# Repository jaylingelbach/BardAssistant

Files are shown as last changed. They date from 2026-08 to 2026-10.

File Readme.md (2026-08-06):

# BardAssistant – The Bard’s Assistant (ESP32-S3)

A tiny “Vicious Mockery” companion built on an ESP32-S3 DevKitM-1.

Right now it:

- Uses **buttons** to request insults (`Random`, `Next`, `Prev`, `Sleep (hold)`).
- Uses a **NeoPixel** as a simple state indicator:
  - **Blue** – Booting
  - **Green** – Idle (ready for button presses)
  - **Yellow** – Updating (pretending to “do work”)
  - **Magenta ** – Updating
- Prints insults and status info over **Serial** (`115200` baud).

Planned:

- Add a **Waveshare 2.13" E-Ink** screen and render insults + header there.
- Power stuff / sleep / wake on long-press.

---

## Hardware

Current setup:

- **Board**: ESP32-S3 DevKitM-1
- **LED**:
  - 1x NeoPixel RGB LED
  - Data pin: `GPIO 21`
- **Buttons** (tactile switches to GND, using `INPUT_PULLUP` in code):
  - Random: `GPIO 4`
  - Next: `GPIO 5`
  - Prev: `GPIO 6`
  - Sleep: `GPIO 7`

Planned display (not wired/used yet):

- Waveshare 2.13" E-Ink Display HAT V4
  - 250x122, SPI, partial refresh
  - Will eventually show:
    - Title screen / logo
    - Current insult text
    - Basic “source” info (`Random / Next / Prev`)

---

## Firmware Overview

All of this lives in `src/main.cpp` for now, plus small modules:

- `lib/button/` – debounced button input
- `lib/led/` – NeoPixel status LED

### Application States

```cpp
enum class ApplicationState { Boot, Idle, Updating };
```

- **Boot**
  - LED: Blue (`ledShowBoot()`)
  - After ~2 seconds, transitions to **Idle**

- **Idle**
  - LED: Green (`ledShowIdle()`)
  - Listens for button taps:
    - Random → start a “Random insult” operation
    - Next → move forward through insult history (or draw new)
    - Prev → move backward through insult history

- **Updating**
  - LED: Yellow (`ledShowUpdating()`)
  - Simulates “work” with a small delay (`MOCK_WORK_MS`)
  - When “done”, applies the insult index and goes back to Idle

### Buttons & Events

Buttons are debounced and produce high-level events (from `button` module):

```cpp
enum class ButtonEvent { None, Tap, HoldStart, HoldEnd };
```

- Tap → triggers Random / Next / Prev operations _while in Idle_
- Sleep:
  - `HoldStart` is wired to eventually trigger deep sleep (`enterSleep()`),
    currently just logs.

### Insults, Deck, and History (Serial Only for Now)

- `insults[]` – array of `const char*` insult strings.
- **Deck**:
  - Shuffled list of indices, ensures “Random” doesn’t repeat until all have been used.

- **History**:
  - Remembers which insults have been shown.
  - `Next` / `Prev` navigate the history when possible.
  - `Next` at the end of history draws a new insult from the deck.

Rendering is currently:

- `renderTitleScreen()` – ASCII art + project name on boot (Serial only).
- `renderInsultAtIndex(...)` – logs:
  - Which insult index is active
  - The insult text itself
  - Optional context (`Random` vs `Next` vs `Prev`)

Later, these will be redirected to the E-Ink screen instead of (or in addition to) Serial.

---

## PlatformIO – Commands I Keep Forgetting

> All commands assume you’re in the project root (where `platformio.ini` lives).

### Build

**Generic:**

```bash
pio run
```

**Specific environment (ESP32-S3 DevKitM-1):**

```bash
pio run -e esp32-s3-devkitm-1
```

---

### Upload Firmware

**Generic upload for default env:**

```bash
pio run -t upload
```

**Upload to ESP32-S3 DevKitM-1 explicitly:**

```bash
pio run -e esp32-s3-devkitm-1 -t upload
```

---

### Erase Flash

Useful when things get weird or after changing flash layout / partitions:

```bash
pio run -e esp32-s3-devkitm-1 -t erase
```

Then re-upload your firmware.

---

### Clean Build Artifacts

If builds start acting cursed:

```bash
pio run -t clean
```

---

### Serial Monitor

**On my Mac / current setup:**

```bash
pio device monitor -p /dev/cu.usbmodem1101 -b 115200
```

Generic form:

```bash
pio device monitor -p <PORT> -b 115200
```

Hit `Ctrl + C` to exit.

---

## Development Notes

- Buttons are wired **to GND** and use `INPUT_PULLUP`:
  - Released → HIGH
  - Pressed → LOW

- Long-press on Sleep is **debounced and recognized**.
- State machine and insult logic are conceptually separate:
  - `main.cpp` handles:
    - Board setup
    - State transitions
    - Calling “work engine” functions

- Insult/deck/history logic lives in `lib/insults/`

---

## Sleep / Wake Behavior

### Entering Sleep

1. **Hold** the Sleep button to arm sleep mode (LED turns magenta).
2. **Release** the button to enter deep sleep.

This "hold to sleep, release to confirm" gesture prevents accidental sleep entry.

### Waking Up

1. **Tap** or **press** the Sleep button while asleep — the pin goes LOW and triggers a wake.
2. The ESP32-S3 boots from reset and runs `setup()` again.
3. Optionally, wake reason can be detected via `esp_sleep_get_wakeup_cause()`.

## Setup (Fresh Clone)

```bash
# Clone
git clone https://github.com/jaylingelbach/BardAssistant.git
cd BardAssistant

# Build (default env)
pio run

# Or build for the ESP32-S3 env explicitly
pio run -e esp32-s3-devkitm-1

# Upload
pio run -e esp32-s3-devkitm-1 -t upload

# Monitor
pio device monitor -p /dev/cu.usbmodem1101 -b 115200
```

## Current display panel being used

- GxEPD2_213_B74

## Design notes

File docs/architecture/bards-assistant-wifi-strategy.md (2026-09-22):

# Bard's Assistant — Wi-Fi Provisioning & Web Mode Strategy

## Purpose

Record the intended Wi-Fi architecture so future changes do not mix up **Wi-Fi provisioning** with **Web Mode**.

mDNS belongs to Web Mode, not Wi-Fi provisioning.

## Mental Model

Bard's Assistant is **offline-first**. Normal use does not turn on Wi-Fi or the web server.

---

## Provisioning Flow

### First-time setup (no saved credentials)

```text
IDLE
 |
 | Provisioning gesture held 2s
 v
provisioningStart()
 |
 +-- Open WiFiManager captive portal (non-blocking)
 +-- Display connection instructions
 |
 | User connects phone to "BardsAssistant" AP,
 | submits credentials at 192.168.4.1
 |
 v
provisioningPoll() → SUCCESS
 |
 v
enterWebModeAlreadyConnected()
 |
 +--[SUCCESS]-----------------------------+
 |   Start mDNS (bardsassistant.local)   |
 |   Start WebServerManager              |
 |   Display: "WiFi saved!               |
 |             bardsassistant.local      |
 |             <IP>"                     |
 |                                       v
 +--[MDNS_FAILED]-------------------> WEB MODE
     Start WebServerManager
     Display: "WiFi saved!
               <IP>"
```

### Re-provisioning (credentials already saved)

```text
IDLE
 |
 | Provisioning gesture held 2s
 v
hasKnownNetwork() → true
 |
 v
ProvisioningConfirmation state
 |
 | Next tap → confirm
 | Sleep tap → cancel → IDLE
 v
provisioningStart()
 ... (same as first-time setup above)
```

---

## Web Mode Flow

### Entering Web Mode (gesture)

```text
IDLE
 |
 | Web Mode gesture held 2s
 v
enterWebMode()
 |
 +-- WiFi.begin() with saved credentials
 +-- Wait for WL_CONNECTED + non-zero IP
 +-- MDNS.begin(BARDS_HOSTNAME)
 +-- WebServerManager.start()
 |
 v
WEB MODE
```

### Exiting Web Mode

```text
WEB MODE
 |
 | Web Mode gesture held 2s
 v
WebServerManager.stop()
exitWebMode()
 |
 +-- MDNS.end()
 +-- WiFi.disconnect() (credentials preserved)
 |
 v
IDLE
```

---

## Key Functions

### `provisioningStart()` / `provisioningPoll()`

Wraps WiFiManager's non-blocking captive portal. `provisioningPoll()` is called
every loop tick while in the `Provisioning` state and returns:

- `IN_PROGRESS` — portal is open, waiting for user
- `SUCCESS` — credentials submitted and WiFi connected
- `FAILED` — timeout expired, or credentials were submitted but connection failed
- `CANCELLED` — portal closed without a submission

### `enterWebMode()`

Used for the gesture-triggered Web Mode path. Calls `WiFi.begin()` with saved
credentials and waits up to 5 seconds for both `WL_CONNECTED` and a non-zero IP
before starting mDNS.

### `enterWebModeAlreadyConnected()`

Used exclusively after a successful provisioning. Skips `WiFi.begin()` entirely
since WiFiManager already holds a live connection. Only starts mDNS.

### `hasKnownNetwork()`

Calls `WiFi.mode(WIFI_STA)` before querying `wm.getWiFiIsSaved()`. The WiFi
driver must be initialized first or the query returns stale data.

### `resetWiFiSettings()`

Clears both the ESP32's own WiFi NVS store (`WiFi.disconnect(true, true)`) and
WiFiManager's NVS namespace (`wm.resetSettings()`). Both must be cleared — they
are separate stores.

---

## Responsibility Boundaries

### NetworkManager

Owns:

- Wi-Fi provisioning (captive portal lifecycle)
- Wi-Fi connection/disconnection
- mDNS lifecycle
- `BARDS_HOSTNAME` constant

### WebServerManager

Owns:

- HTTP server
- HTTP routes and request/response handling
- Web UI/API serving

Does **not** own:

- Wi-Fi provisioning
- LittleFS persistence
- Deck business logic

### Main / Application Layer

Owns:

- User-driven state transitions (`ApplicationState`)
- Deciding when to enter/exit provisioning and Web Mode
- Coordinating managers

---

## Important Invariants

**mDNS belongs to Web Mode.**
Do not start `MDNS.begin()` in provisioning code. The question to ask is:

> "Is the device entering Web Mode?"

If **no** → don't start mDNS.
If **yes** → `enterWebMode()` or `enterWebModeAlreadyConnected()` handles it.

**`hasKnownNetwork()` requires an initialized WiFi driver.**
Always ensure `WiFi.mode(WIFI_STA)` has been called before querying saved
credentials, or the result is unreliable.

**Two NVS stores, one reset.**
`wm.resetSettings()` alone does not fully clear credentials. Always pair it with
`WiFi.disconnect(true, true)`.

---

## Hostname

The hostname is defined as `BARDS_HOSTNAME` in `networkManager.h`:

```cpp
static constexpr const char *BARDS_HOSTNAME = "bardsassistant";
```

This is used for:
- The WiFiManager AP password
- `MDNS.begin()`
- Display messages

Change it in one place to update everywhere.

---

## OTA Authentication (Deferred)

ElegantOTA is integrated but has no authentication — `/update` is open to anyone
on the network. Acceptable during development on a trusted network, but must be
addressed before shipping.

When the production board is finalized, add `ElegantOTA.setAuth()` sourcing
credentials from NVS rather than hardcoding them.

### ElegantOTA License (AGPL-3.0)

ElegantOTA is AGPL-3.0. Private use on your own device carries no obligation.
If you distribute firmware to others, AGPL requires making the complete source
available to recipients. Before shipping to anyone else, either open-source
under a compatible license or purchase the ElegantOTA Pro commercial license.

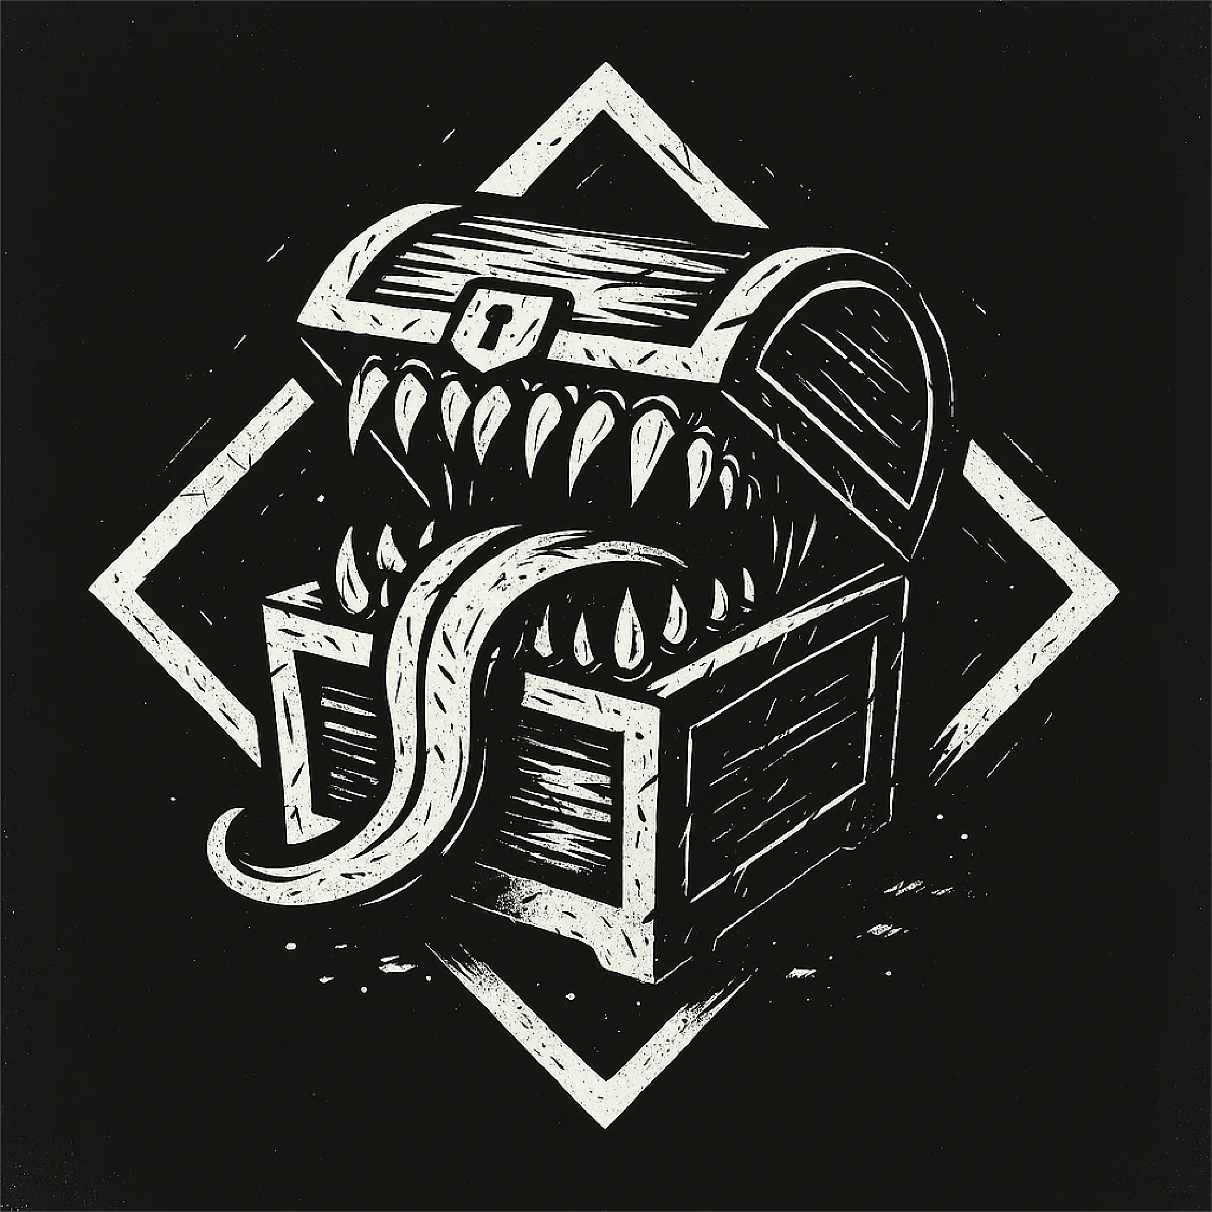
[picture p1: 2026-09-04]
KiCad/BardsAssistant/mimic.png

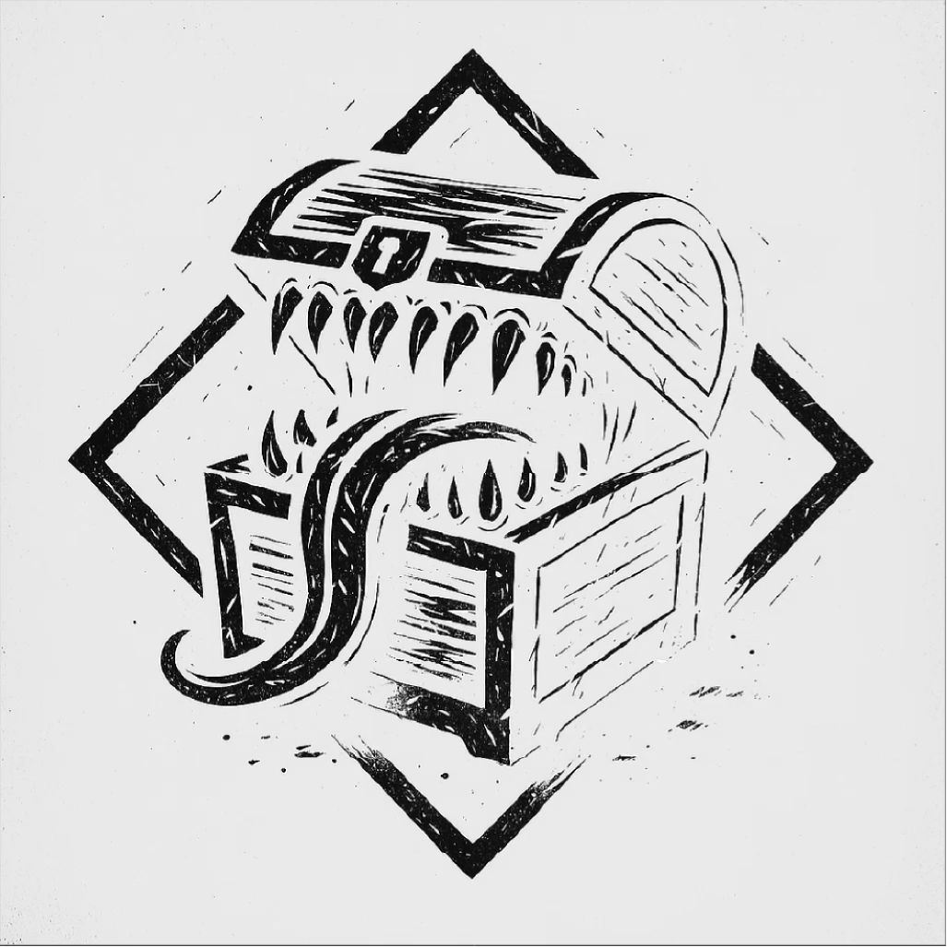
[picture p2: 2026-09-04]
KiCad/BardsAssistant/mimic.BMP

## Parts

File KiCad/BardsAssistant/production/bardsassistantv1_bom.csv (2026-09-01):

Designator | Footprint | Quantity | Value | LCSC Part #
C1, C5, C6 | 0603 | 3 | 10uF | C19702
C10, C9 | 0805 | 2 | 4.7uF | C1779
C11, C12, C15, C16, C17, C18, C19, C20 | 0805 | 8 | 1uF | C15849
C13, C7, C8 | 0603 | 3 | 1uF | C15849
C2, C4 | 0603 | 2 | .1uF | C14663
C21, C22 | 0805 | 2 | 10uF | C19702
C3 | 0805 | 1 | 22uF | C45783
D1 | LED_XL-3227RGB-RF | 1 | XL-3227RGB-RF | C965844
D2 | D_SMA | 1 | SS114 | C2480
D3, D4 | D_SOD-923 | 2 | ESD9B3.3 | C96512
D5 | 0603 | 1 | LED Red | C2286
D6, D7, D8 | D_SOD-123 | 3 | MBR0530 | C77336
D9 | 0805 | 1 | LED Green | C2297
F1 | 0805 | 1 | Polyfuse 1A | C5307781
FB1 | 0805 | 1 | BLM21PG221 | C85840
IC1 | ESP32S3MINI1N8 | 1 | ESP32-S3-MINI-1-N8 | C2913206
J1 | USB_C_Receptacle_GCT_USB4110 | 1 | USB_C_Receptacle_USB2.0_16P | C5143397
J2 | FPC-SMD_KH-FG0.5-H2.0-24PIN | 1 | Conn_01x24 | C2797213
J3 | JST_PH_S2B-PH-SM4-TB_1x02-1MP_P2.00mm_Horizontal | 1 | JST-PH-2-SMT-RA | C157932
L1 | L_Sunlord_SWPA6045S | 1 | 68uH | C53663
L2 | SMNR5040_2R2MT_BA | 1 | 2.2uH | C9941
Q1 | SOT-323_SC-70 | 1 | Si1308EDL | C469327
Q3 | SOT-23 | 1 | AO3401A | C15127
R1, R2 | 0402 | 2 | 5K1 | C25905
R10 | 0402 | 1 | 5K | C25905
R11, R14, R16 | 0402 | 3 | 330R | C23138
R12, R13 | 0402 | 2 | 470R | C25117
R15 | 0402 | 1 | 100R | C25076
R17, R4, R9 | 0603 | 3 | 1R | C22936
R3, R5, R7, R8 | 0402 | 4 | 10K | C25744
R6 | 0402 | 1 | 100K | C25741
SW1, SW2, SW3, SW4, SW5, SW6 | SW_SPST_TS-1088-xR020 | 6 | SW_Push | C720477
TP1, TP2, TP3, TP4, TP7, TP8, TP9 | TestPoint_Pad_2.0x2.0mm | 7 | TestPoint
TP5 | TestPoint_Pad_2.0x2.0mm | 1 | GND
U1 | Texas_DRC0010J_ThermalVias | 1 | TPS63001 | C28060
U2 | SOT-23-6 | 1 | USBLC6-2SC6 | C7519
U3 | SOT-23-5 | 1 | MCP73831/2 | C424093

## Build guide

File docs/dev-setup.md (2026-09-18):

# Bard's Assistant — Developer Setup

## Prerequisites

- VS Code
- PlatformIO IDE extension (`platformio.ide`)
- clangd extension (`llvm-vs-code-extensions.vscode-clangd`)

The Microsoft C/C++ extension (`ms-vscode.cpptools`) is installed but disabled at the workspace level — PlatformIO manages IntelliSense through clangd instead.

---

## Go to Definition

Go to Definition (`Fn+F12` or `Cmd+Click`) is powered by clangd reading `compile_commands.json` at the project root.

### First-time setup

After cloning or after a clean build, generate the file:

```sh
pio run -e esp32-s3-devkitm-1 -t compiledb
```

Then in VS Code: `Cmd+Shift+P` → **PlatformIO: Rebuild IntelliSense Index**.

### Keeping it up to date

`compile_commands.json` goes stale when you add new source files or dependencies. Regenerate it with the same command:

```sh
pio run -e esp32-s3-devkitm-1 -t compiledb
```

Normal builds (`pio run`) should also regenerate it automatically via `generate_compile_commands.py`.

---

## Flashing

```sh
# Flash firmware
pio run -e esp32-s3-devkitm-1 --target upload

# Flash filesystem (LittleFS — web UI, insults.json)
pio run -e esp32-s3-devkitm-1 --target uploadfs
```

Both commands are also in the PlatformIO sidebar under **Project Tasks**.

---

## Serial Monitor

```sh
pio device monitor
```

Baud rate is set to `115200` in `platformio.ini`.

---

## Logging

All serial output goes through `lib/include/log.h`. The log level is set at compile time via `LOG_LEVEL` in `platformio.ini` — output below the active level is stripped entirely from the binary (no string literals in flash, no runtime cost).

### Levels

| Value | Name  | What prints |
|---|---|---|
| `0` | OFF | Nothing |
| `1` | ERROR | Hard failures only |
| `2` | WARN  | Errors + recoverable warnings |
| `3` | INFO  | Errors + warnings + lifecycle info |
| `4` | DEBUG | Everything (button taps, WiFi dots, insult title cards) |

### Changing the level

In `platformio.ini`, under `[env:esp32-s3-devkitm-1]`:

```ini
build_flags =
    ...
    -DLOG_LEVEL=4   ; dev — change to 3 for a release build
```

`LOG_LEVEL=4` is the default for development. Set to `3` before shipping to strip all debug output.

### Macros

| Macro | Use for |
|---|---|
| `LOG_ERROR(msg)` | Hard failures |
| `LOG_WARN(msg)` | Recoverable edge cases |
| `LOG_INFO(msg)` | Lifecycle events (boot, connect, save) |
| `LOG_DEBUG(msg)` | Verbose dev output (button events, nav steps) |
| `LOG_ERRORF(fmt, ...)` | printf-style with runtime values |
| `LOG_INFO_RAW(val)` / `LOG_DEBUG_RAW(val)` | `Serial.println(val)` for non-string types (IPAddress, int, etc.) |
| `LOG_INFO_PRINT(val)` / `LOG_DEBUG_PRINT(val)` | `Serial.print(val)` without newline |

Use `F()` wrapping is handled inside the macros for string literals — don't add it at the call site.

---

## Test Display Environment

A separate `test-display` env compiles `test_display.cpp` instead of `main.cpp` for isolated display testing:

```sh
pio run -e test-display --target upload
```

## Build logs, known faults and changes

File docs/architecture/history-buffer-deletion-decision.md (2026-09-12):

# Why History Buffer Deletion Reconstructs the Circular Buffer

## Decision

When an insult is deleted, `removeFromHistory()` will **reconstruct the history circular buffer** rather than shifting entries in place around the circular buffer.

The history storage remains a fixed-size array:

```cpp
RTC_DATA_ATTR uint32_t history[HISTORY_CAP] = {0};
```

We are **not** changing history to a `std::vector`.

## Why

The history buffer is a circular buffer because its normal job is to maintain a small, bounded navigation history across deep sleep/wake.

Normal history operations are simple and efficient:

- append a new insult ID
- discard the oldest entry when the buffer is full
- navigate Prev/Next
- persist the buffer in RTC memory

Deletion is different. Deleting an arbitrary ID from the middle of a circular buffer requires reasoning about both:

- **logical position** — where an entry appears in the user's history
- **physical position** — where the entry happens to live in `history[]`

Because the buffer can wrap around the end of the array, an in-place deletion would require carefully handling:

- physical index wrapping
- `historyHead`
- `historySize`
- `historyPosition`
- shifting entries across the physical end of the array
- preserving logical order

That complexity creates more opportunities for subtle off-by-one and state-consistency bugs.

## The Alternative: In-Place Shifting

A normal array deletion looks like:

```text
[A][B][C][D][E]

Delete C

[A][B][D][E][E]
```

The elements after the deleted entry are shifted left and the logical size is reduced.

That algorithm works naturally when physical order and logical order are the same.

Our history buffer does not guarantee that.

For example, the physical array might contain:

```text
[F][B][C][D][E]
```

while the logical history is:

```text
B → C → D → E → F
```

An in-place deletion therefore has to account for the circular wrap.

## The Chosen Approach: Reconstruct

Instead, `removeFromHistory()` will work primarily in **logical history order**.

Conceptually:

```text
Current logical history:

A → B → C → D → E

Delete C

Remaining logical history:

A → B → D → E
```

The function can then rebuild the fixed circular-buffer representation from the remaining IDs.

The rest of the application does not need to know how the circular buffer is physically arranged.

## Why This Is Acceptable

History is intentionally bounded by `HISTORY_CAP`.

Even if the history capacity were 50 or 100 entries, reconstructing it means copying at most that many `uint32_t` IDs.

For example:

```text
100 IDs × 4 bytes = 400 bytes
```

Deletion is also an infrequent operation compared with normal operations such as Random, Next, and Prev.

Therefore, we prefer:

1. Correctness
2. Clear reasoning
3. Maintainability
4. Performance

For this use case, reconstruction is a better tradeoff than complicated in-place circular-buffer manipulation.

## Why We Did Not Change History to a Vector

The fact that arbitrary deletion is easier with a vector does not mean a vector is the better underlying structure.

The circular buffer still provides useful properties for the normal history workload:

- fixed memory usage
- bounded history
- efficient appending
- automatic expiration of old history
- predictable embedded-memory behavior
- straightforward RTC persistence

The awkwardness comes from supporting **one less-common operation (arbitrary deletion)**, not from the circular buffer being a poor fit for history itself.

So the decision is:

```text
Keep:
    fixed RTC_DATA_ATTR array
    circular-buffer behavior

Add:
    history-specific removal operation

Use:
    reconstruction when removing an arbitrary ID
```

## API Boundary

The rest of the application should not manipulate the circular-buffer internals directly.

Instead, history should expose operations such as:

```cpp
appendToHistory(uint32_t id);
historyGetAtLogical(size_t logicalPos, uint32_t &outId);
removeFromHistory(uint32_t id);
```

`deleteInsult()` should be able to say:

```text
remove this ID from history
```

without needing to know about:

- `historyHead`
- physical array indexes
- wrapping
- how the circular buffer is reconstructed

This keeps the circular-buffer implementation encapsulated inside the history logic.

## Future Reconsideration

This decision can be revisited if the requirements change.

Consider a different data structure if:

- `HISTORY_CAP` becomes very large
- arbitrary history mutations become frequent
- history needs operations that are consistently awkward with a circular buffer
- the device needs substantially more complex history querying/manipulation

For the current Bard's Assistant requirements, none of those justify changing the underlying structure.

## Short Version

**We reconstruct the history buffer on deletion because deletion is rare, history is small and bounded, and reconstruction keeps the circular-buffer logic understandable and reliable.**

We are deliberately optimizing for **correctness and maintainability over micro-optimization**.

The circular buffer is still the right structure for normal history behavior; reconstruction is simply the safest way to handle an unusual mutation of that structure.

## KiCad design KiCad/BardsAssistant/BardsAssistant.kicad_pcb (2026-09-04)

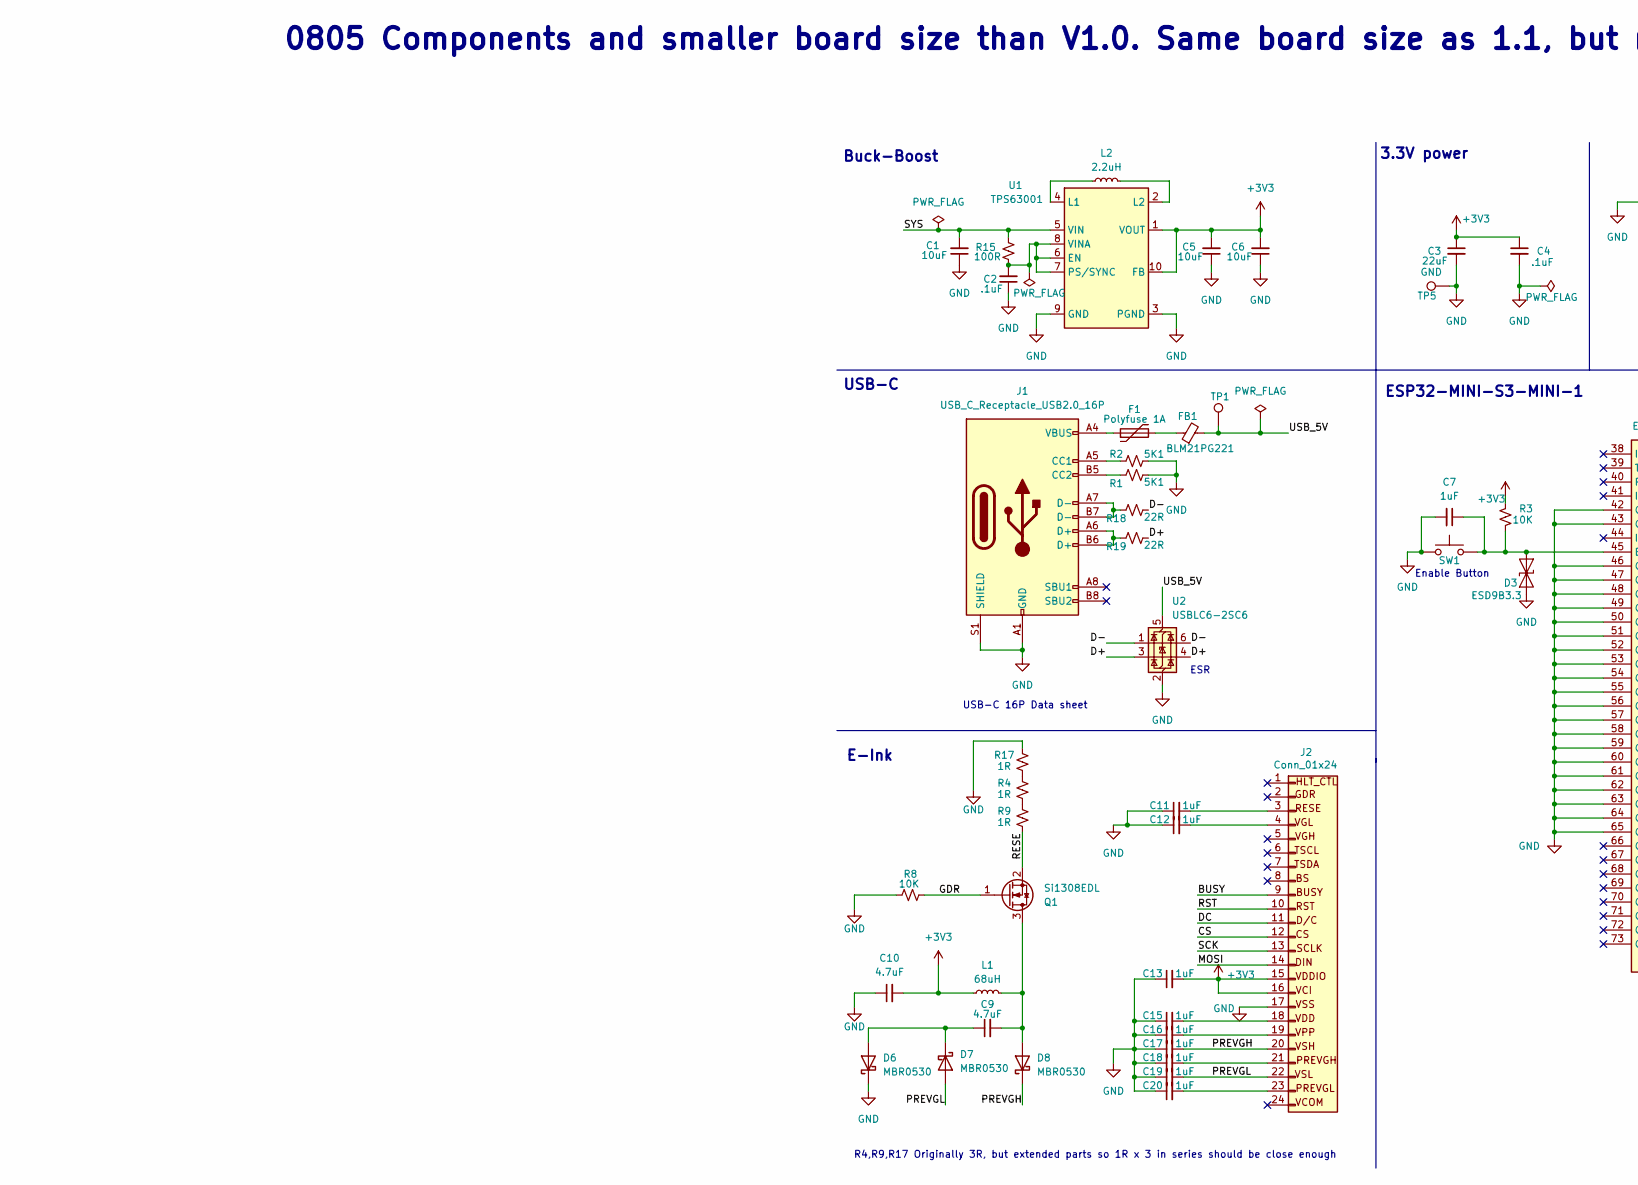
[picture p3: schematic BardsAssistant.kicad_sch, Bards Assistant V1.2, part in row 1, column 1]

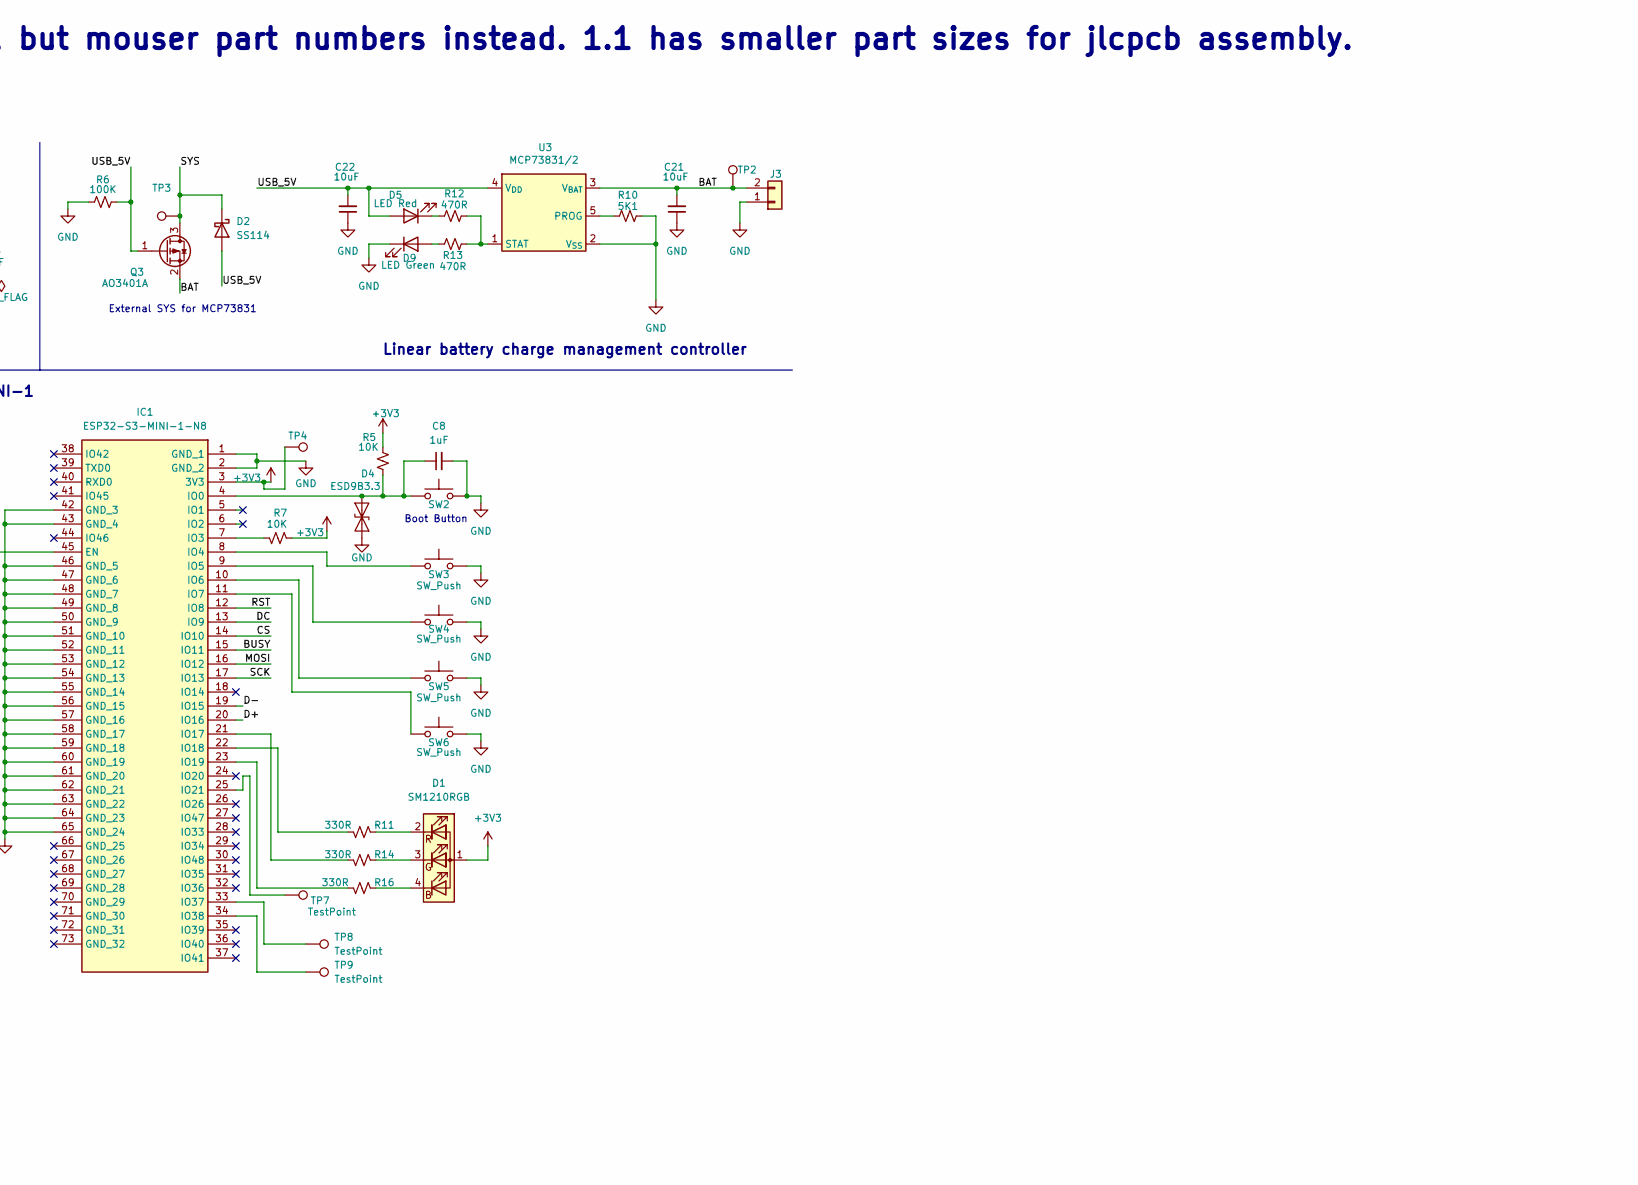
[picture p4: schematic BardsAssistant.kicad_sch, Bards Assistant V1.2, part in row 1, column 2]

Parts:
C1, C5, C6, C21, C22: 10uF; C_0805_2012Metric; MPN CL21B106KOYNNWE; Mouser Part Number 187-CL21B106KOYNNWE
C2, C4: .1uF; C_0805_2012Metric; MPN CC0805KRX7R8BB104; Mouser Part Number 603-CC805KRX7R8BB104
C3: 22uF; C_0805_2012Metric; MPN CC0805MFX5R8BB226; Mouser Part Number 603-CC0805MFX5R8BB22
C7, C8, C13: 1uF; C_0805_2012Metric; MPN CC0805KFX7R8BB105; Mouser Part Number 603-CC805KFX7R8BB105
C9, C10: 4.7uF; C_0805_2012Metric; Mouser Part Number 603-CC805KKX7R8BB475
C11, C12, C15, C16, C17, C18, C19, C20: 1uF; C_0805_2012Metric; Mouser Part Number 603-CC805KFX7R8BB105
D1: SM1210RGB; LED_XL-3227RGB-RF; Mouser Part Number 749-SM1210RGB
D2: SS114; D_SMA; MPN SS14; LCSC Part # C2480
D3, D4: ESD9B3.3; D_SOD-923; Mouser Part Number 863-ESD9B3.3ST5G
D5: LED Red; LED_0805_2012Metric; MPN 150080SS75000; Mouser Part Number 710-150080SS75000
D6, D7, D8: MBR0530; D_SOD-123; MPN MBR0530; LCSC Part # C77336
D9: LED Green; LED_0805_2012Metric; MPN KT-0805G; LCSC Part # C2297
F1: Polyfuse 1A; Fuse_0805_2012Metric; MPN JK-SMD0805-100-6; LCSC Part # C5307781
FB1: BLM21PG221; L_0805_2012Metric; MPN BLM21PG221SN1D; LCSC Part # C85840
IC1: ESP32-S3-MINI-1-N8; ESP32S3MINI1N8; Manufacturer_Part_Number ESP32-S3-MINI-1-N8; Mouser Part Number 356-ESP32-S3-MINI1N8
J1: USB_C_Receptacle_USB2.0_16P; USB_C_Receptacle_GCT_USB4110; MPN USB4110-GF-A; LCSC Part # C5143397
J2: Conn_01x24; FPC-SMD_KH-FG0.5-H2.0-24PIN; MPN KH-FG0.5-H2.0-24PIN; LCSC Part # C2797213
J3: JST-PH-2-SMT-RA; JST_PH_S2B-PH-SM4-TB_1x02-1MP_P2.00mm_Horizontal; MPN S2B-PH-K-S-GW; LCSC Part # C157932
L1: 68uH; L_Sunlord_SWPA6045S; MPN SWPA6045S680MT; LCSC Part # C53663
L2: 2.2uH; SMNR5040_2R2MT_BA; MPN SMNR5040-2R2MT; LCSC Part # C9941
Q1: Si1308EDL; SOT-323_SC-70; MPN SI1308EDL-T1-GE3; LCSC Part # C469327
Q3: AO3401A; SOT-23; MPN AO3401A; LCSC Part # C15127
R1, R2, R10: 5K1; R_0805_2012Metric; MPN 0805W8F5101T5E; LCSC Part # C27834
R3, R5, R7, R8: 10K; R_0805_2012Metric; MPN 0805W8F1002T5E; LCSC Part # C17414
R4, R9, R17: 1R; R_0805_2012Metric; MPN 0805W8F100KT5E; LCSC Part # C25271
R6: 100K; R_0805_2012Metric; MPN 0805W8F1003T5E; LCSC Part # C149504
R11, R14, R16: 330R; R_0805_2012Metric; MPN 0805W8F3300T5E; LCSC Part # C17630
R12, R13: 470R; R_0805_2012Metric; MPN 0805W8F4700T5E; LCSC Part # C17710
R15: 100R; R_0805_2012Metric; MPN 0805W8F1000T5E; LCSC Part # C17408
R18, R19: 22R; R_0805_2012Metric; MPN RT0805BRE0722RL; Mouser Part Number 603-RT0805BRE0722RL
SW1, SW2, SW3, SW4, SW5, SW6: SW_Push; SW_SPST_TS-1088-xR020; MPN TS-1088-AR02016; LCSC Part # C720477
TP1, TP2, TP3, TP4, TP7, TP8, TP9: TestPoint; TestPoint_Pad_2.0x2.0mm
TP5: GND; TestPoint_Pad_2.0x2.0mm
U1: TPS63001; Texas_DRC0010J_ThermalVias; MPN TPS63001DRCR; LCSC Part # C28060
U2: USBLC6-2SC6; SOT-23-6; MPN USBLC6-2SC6; LCSC Part # C7519
U3: MCP73831/2; SOT-23-5; MPN MCP73831T-2ACI/OT; LCSC Part # C424093

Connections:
+3V3: C3.1, C4.1, C5.2, C6.2, C10.2, C13.2, D1.1 (A), IC1.3 (3V3), J2.15 (VDDIO), J2.16 (VCI), L1.1, R3.1, R5.1, R7.1, TP4.1, U1.1 (VOUT), U1.10 (FB)
/BAT: C21.2, J3.2, Q3.2 (BAT), TP2.1, U3.3 (V_{BAT})
/BUSY: IC1.15 (IO11), J2.9 (BUSY)
/CS: IC1.14 (IO10), J2.12 (CS)
/D+: IC1.20 (IO16), R19.1, U2.3 (I/O2), U2.4 (I/O2)
/D-: IC1.19 (IO15), R18.1, U2.1 (I/O1), U2.6 (I/O1)
/DC: IC1.13 (IO9), J2.11 (D/C)
/GDR: Q1.1 (G), R8.2
/MOSI: IC1.16 (IO12), J2.14 (SDI)
/PREVGH: C17.2, D8.1 (K), J2.20 (VSH)
/PREVGL: C19.2, D7.2 (A), J2.22 (VSL)
/RESE: Q1.2 (S), R9.1
/RST: IC1.12 (IO8), J2.10 (RST)
/SCK: IC1.17 (IO13), J2.13 (SCLK)
/SYS: C1.2, D2.1 (K), Q3.3 (SYS), R15.2, TP3.1, U1.5 (VIN)
/USB_5V: C22.2, D2.2 (A), D5.2 (A), FB1.2, Q3.1 (G), R6.2, TP1.1, U2.5 (VBUS), U3.4 (V_{DD})
GND: C1.1, C2.1, C3.2, C4.2, C5.1, C6.1, C7.2, C8.2, C10.1, C11.1, C12.1, C13.1, C15.1, C16.1, C17.1, C18.1, C19.1, C20.1, C21.1, C22.1, D3.1 (A1), D4.1 (A1), D6.1 (K), D9.1 (K), IC1.1 (GND_1), IC1.2 (GND_2), IC1.42 (GND_3), IC1.43 (GND_4), IC1.46 (GND_5), IC1.47 (GND_6), IC1.48 (GND_7), IC1.49 (GND_8), IC1.50 (GND_9), IC1.51 (GND_10), IC1.52 (GND_11), IC1.53 (GND_12), IC1.54 (GND_13), IC1.55 (GND_14), IC1.56 (GND_15), IC1.57 (GND_16), IC1.58 (GND_17), IC1.59 (GND_18), IC1.60 (GND_19), IC1.61 (GND_20), IC1.62 (GND_21), IC1.63 (GND_22), IC1.64 (GND_23), IC1.65 (GND_24), J1.A1 (GND), J1.A12 (GND), J1.B1 (GND), J1.B12 (GND), J1.S1 (SHIELD), J2.17 (VSS), J3.1, R1.1, R2.1, R6.1, R8.1, R10.2, R17.2, SW1.2, SW2.2, SW3.2, SW4.2, SW5.2, SW6.2, TP5.1, U1.3 (PGND), U1.9 (GND), U1.11 (PGND), U2.2 (GND), U3.2 (V_{SS})
unnamed: D1.4 (BK), R16.1
unnamed: D1.3 (GK), R14.1
unnamed: D1.2 (RK), R11.1
unnamed: C7.1, D3.2 (A2), IC1.45 (EN), R3.2, SW1.1
unnamed: C8.1, D4.2 (A2), IC1.4 (IO0), R5.2, SW2.1
unnamed: D5.1 (K), R12.1
unnamed: C9.1, D6.2 (A), D7.1 (K)
unnamed: C9.2, D8.2 (A), L1.2, Q1.3 (D)
unnamed: D9.2 (A), R13.1
unnamed: F1.1, J1.A4 (VBUS), J1.A9 (VBUS), J1.B4 (VBUS), J1.B9 (VBUS)
unnamed: F1.2, FB1.1
unnamed: IC1.7 (IO3), R7.2
unnamed: IC1.8 (IO4), SW3.1
unnamed: IC1.9 (IO5), SW4.1
unnamed: IC1.10 (IO6), SW5.1
unnamed: IC1.11 (IO7), SW6.1
unnamed: IC1.21 (IO17), R14.2
unnamed: IC1.22 (IO18), R11.2
unnamed: IC1.23 (IO19), R16.2
unnamed: IC1.25 (IO21), TP7.1
unnamed: IC1.33 (IO37), TP8.1
unnamed: IC1.34 (IO38), TP9.1
unnamed: J1.A5 (CC1), R2.2
unnamed: J1.B5 (CC2), R1.2
unnamed: J1.A6 (D+), J1.B6 (D+), R19.2
unnamed: J1.A7 (D-), J1.B7 (D-), R18.2
unnamed: C18.2, J2.21 (PREVGH)
unnamed: C20.2, J2.23 (PREVGL)
unnamed: C11.2, J2.3 (RESE)
unnamed: C15.2, J2.18 (VDD)
unnamed: C12.2, J2.4 (VGL)
unnamed: C16.2, J2.19 (VPP)
unnamed: R4.1, R9.2
unnamed: R4.2, R17.1
unnamed: C2.2, R15.1, U1.6 (EN), U1.7 (PS/SYNC), U1.8 (VINA)
unnamed: L2.1, U1.4 (L1)
unnamed: L2.2, U1.2 (L2)
unnamed: R10.1, U3.5 (PROG)
unnamed: R12.2, R13.2, U3.1 (STAT)

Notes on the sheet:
Enable Button
External SYS for MCP73831
Boot Button
3.3V power
USB-C
ESR
ESP32-MINI-S3-MINI-1
E-Ink
0805 Components and smaller board size than V1.0. Same board size as 1.1, but mouser part numbers instead. 1.1 has smaller part sizes for jlcpcb assembly.
Linear battery charge management controller
USB-C 16P Data sheet
Buck-Boost
R4,R9,R17 Originally 3R, but extended parts so 1R x 3 in series should be close enough

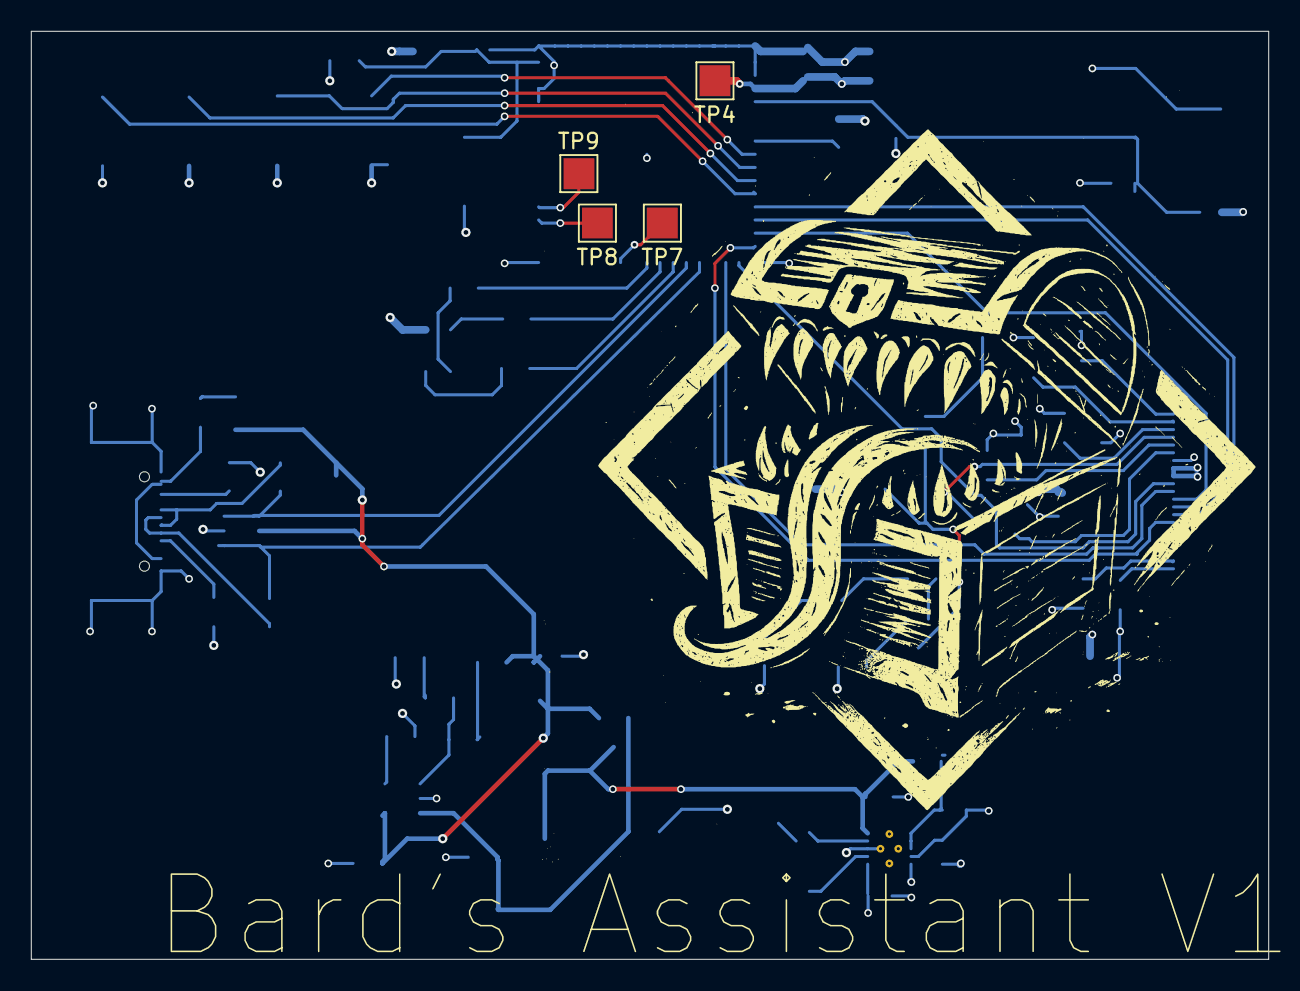
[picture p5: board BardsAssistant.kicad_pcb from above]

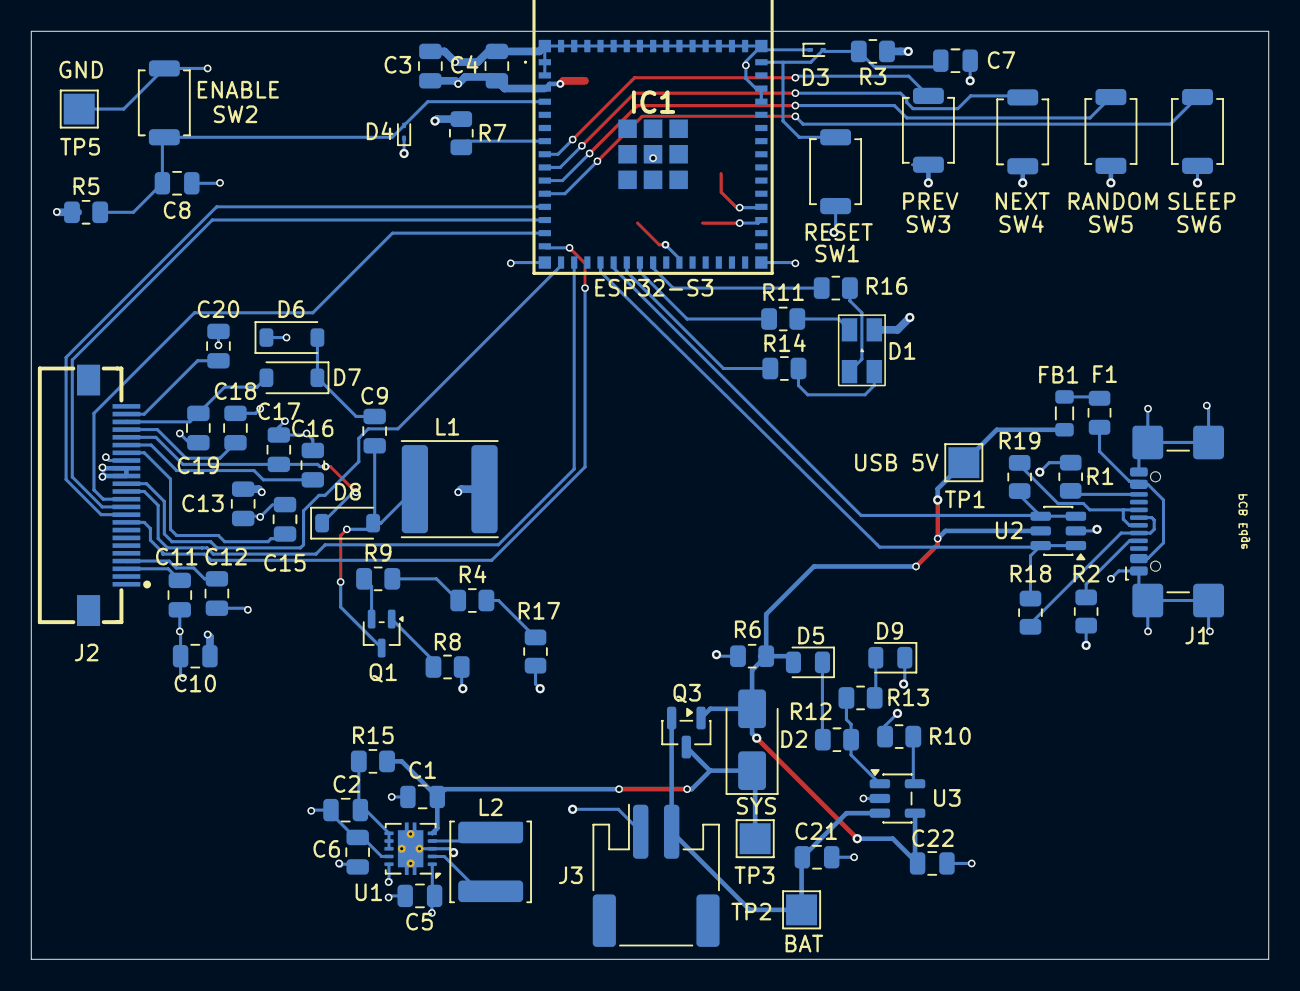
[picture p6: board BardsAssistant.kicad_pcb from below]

Board: 4 copper layers, 80.0 x 60.0 mm, 76 parts (72 on the bottom side), 56 nets.

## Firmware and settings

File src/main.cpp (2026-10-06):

#include <Arduino.h>
#include <ElegantOTA.h>
#include <LittleFS.h>
#include <Preferences.h>
#include <WiFi.h>
#include <esp_sleep.h>

#include <cstdint>

#include "HWCDC.h"
#include "button.h"
#include "credentialStore.h"
#include "display.h"
#include "driver/rtc_io.h"
#include "insults.h"
#include "led.h"
#include "log.h"
#include "networkManager.h"
#include "persist_keys.h"
#include "provisioning.h"
#include "webServerManager.h"

// ───────────────── Development flags ─────────────

// ───────────────── Configuration ─────────────────

// Buttons
static Button sleepButton;
static Button randomButton;
static Button nextButton;
static Button prevButton;

static constexpr uint8_t PIN_RANDOM_BUTTON = 4;
static constexpr uint8_t PIN_NEXT_BUTTON = 5;
static constexpr uint8_t PIN_PREV_BUTTON = 6;
static constexpr uint8_t PIN_SLEEP_BUTTON = 7;

// Boot splash duration (Boot LED pattern)
static constexpr uint32_t LED_BOOT_DURATION_MS = 2000;

// If true, on cold boot we immediately show an insult (after init).
// Wake-from-sleep always shows the last insult regardless of this flag.
static constexpr bool PRINT_INSULT_ON_BOOT = true;

// EXT0 wake requires an RTC-capable GPIO.
// Using the same physical Sleep button for both sleep + wake.
static constexpr gpio_num_t WAKEUP_GPIO = GPIO_NUM_7;

// Display configuration (pins/rotation/default mode live in DisplayConfig
// defaults)
static DisplayConfig displayConfig{};

// Web Server
static WebServerManager webServerManager;

// ───────────────── App State ─────────────────────

enum class ApplicationState {
  Boot,
  Idle,
  Updating,
  Provisioning,
  ProvisioningConfirmation,
  WebModeConnecting
};
enum class ButtonId { Sleep, Random, Next, Prev };
// Idle means not provisioning. Waiting means provisioning has started and
// we are waiting for a result.
enum class ProvisioningState { Idle, Waiting, Success, Failed };

static ApplicationState currentState = ApplicationState::Boot;
static ProvisioningState provisioningState = ProvisioningState::Idle;

// Timing
static uint32_t stateEnteredAt = 0;

// Sleep gesture
static bool sleepArmed = false;

// Ignore early input right after boot/wake (prevents accidental actions)
static uint32_t ignoreInputUntil = 0;

// If we detect a deep-sleep wake, we clear the NVS flag later (after boot
// splash) so USB monitor reconnect/reset doesn’t hide the “woke-from-sleep”
// classification.
static bool needsSleepFlagClear = false;

static bool gestureActive = false;
static uint32_t gestureStartedAt = 0;
static bool gestureTriggered = false;
static bool isWebModeActive = false;
static bool gestureIsProvisioning = false;

// ───────────────── State transitions ─────────────

/**
 * @brief Enter the Boot state (boot LED splash).
 *
 * Sets the application state to Boot, shows the boot LED pattern,
 * and records when we entered the state.
 */
static void enterBoot() {
  ledShowBoot();
  currentState = ApplicationState::Boot;
  stateEnteredAt = millis();
}

/**
 * @brief Enter the Idle state (ready for button input).
 *
 * Shows the idle LED pattern and (if we previously woke from sleep)
 * clears the persisted NVS "slept" flag once we're safely running.
 */
static void enterIdle() {
  ledShowIdle();

  // Clear the sleep marker after the boot splash so a monitor-triggered reset
  // right after wake doesn’t misclassify future boots.
  if (needsSleepFlagClear) {
    Preferences prefs;
    if (prefs.begin(NVS_NS, false)) {
      prefs.putUChar("slept", 0);
      prefs.end();
    }
    needsSleepFlagClear = false;
  }

  currentState = ApplicationState::Idle;
  stateEnteredAt = millis();
}

/**
 * @brief Enter the Updating state (operation-in-progress).
 *
 * Shows the updating LED pattern and records when we entered the state.
 */
static void enterUpdating() {
  ledShowUpdating();
  currentState = ApplicationState::Updating;
  stateEnteredAt = millis();
}

/**
 * @brief Restore the LED pattern for the current application state.
 *
 * Provisioning uses the updating pattern; confirmation and WebModeConnecting
 * leave the LED unchanged.
 */
static void restoreLedForState() {
  switch (currentState) {
    case ApplicationState::Boot:
      ledShowBoot();
      break;
    case ApplicationState::Idle:
      ledShowIdle();
      break;
    case ApplicationState::Updating:
      ledShowUpdating();
      break;
    case ApplicationState::Provisioning:
      ledShowUpdating();
  }
}

/**
 * @brief Called exactly once when an insult operation completes.
 *
 * This is the "source of truth" for rendering after button-driven actions:
 * when the operation completes, the insults module has updated its internal
 * state (current insult + history pointer), so we render whatever is current.
 */
static void onOperationCompleted() {
  if (insultsHasAny()) {
    displayRenderInsult(insultsGetCurrentText());
  }
  enterIdle();
}

/**
 * @brief Enter deep sleep and configure wake via the Sleep button (EXT0).
 *
 * EXT0 wake is level-based (not edge-based): the chip wakes when the RTC GPIO
 * is held at the configured logic level.
 *
 * With the button wired to GND and the pin using a pull-up, the “pressed” level
 * is LOW, so we wake on LOW (wake happens immediately on press).
 *
 * New sleep behavior (chosen UX):
 * - Persist insult state so we can restore and re-render the last insult on
 * wake.
 * - Blank the e-ink screen so the device looks "off" while sleeping.
 * - Hibernate the display driver to minimize power while asleep.
 * - Set an NVS "slept" flag so setup() can classify the next boot as
 * wake-from-sleep.
 *
 * Note: deep sleep never returns; the device restarts from setup() on wake.
 */
static void enterSleep() {
  // Turn off LEDs before power domains drop.
  ledOff();

  // Configure wake on Sleep button press (LOW).
  esp_err_t err = esp_sleep_enable_ext0_wakeup(WAKEUP_GPIO, 0 /* LOW */);
  if (err != ESP_OK) {
    LOG_ERRORF("EXT0 wake config failed: %d\n", err);
  }

  // Keep the wake pin at the inactive level while asleep.
  // (Pull-up enabled since inactive is HIGH, pull-down disabled.)
  rtc_gpio_pullup_en(WAKEUP_GPIO);
  rtc_gpio_pulldown_dis(WAKEUP_GPIO);

  // Persist app/module state for restore after wake.
  insultsPersistForSleep();

  // Make the device look "off" while sleeping.
  // (E-ink holds the last image with no power, so we must blank it BEFORE
  // sleep.)
  displayRenderBlankScreen();
  displaySleep(DisplaySleepMode::Hibernate);

  // Mark intent-to-sleep in NVS so next boot is treated as "wake".
  {
    Preferences prefs;
    if (prefs.begin(NVS_NS, false)) {
      prefs.putUChar("slept", 1);
      prefs.end();
    }
  }

  // Give serial + flash a moment to flush/commit before sleeping.
  Serial.flush();
  delay(50);

  esp_deep_sleep_start();  // never returns
}

// ───────────────── Work Orchestration ────────────

/**
 * @brief Starts Wi-Fi provisioning and shows connection instructions.
 *
 * On startup failure, returns to idle and restores the current insult or
 * empty-state screen. An already active portal leaves the state unchanged.
 */
static void startProvisioning() {
  ProvisioningStartResult provisioningResult = provisioningStart();

  if (provisioningResult == ProvisioningStartResult::STARTED) {
    currentState = ApplicationState::Provisioning;
    provisioningState = ProvisioningState::Waiting;
    displayRenderMessage(
        "Connect to WiFi:\nBardsAssistant\n\nPassword:\nbardsassistant\n\nThen "
        "visit\n192.168.4.1");

  } else if (provisioningResult == ProvisioningStartResult::ALREADY_ACTIVE) {
    LOG_DEBUG("[startProvisioning] Provisioning is already active.");

  } else if (provisioningResult == ProvisioningStartResult::START_FAILED) {
    LOG_ERROR("[startProvisioning] Provisioning Failed to start.");

    currentState = ApplicationState::Idle;

    if (insultsHasAny()) {
      displayRenderInsult(insultsGetCurrentText());
    } else {
      displayRenderEmptyState();
    }
  }
}

/**
 * @brief Starts a Wi-Fi connection attempt for web mode.
 *
 * On STARTED, enters WebModeConnecting and marks web mode inactive so loop()
 * can finish the transition. On START_FAILED, disconnects Wi-Fi without
 * changing the application state or display. On NO_CREDENTIALS (including an
 * unreadable or invalid stored count), starts provisioning.
 *
 * @param now Current uptime in milliseconds, used to time the connection.
 */
static void handleWebModeToggle(uint32_t now) {
  WebModeStartResult result = startWebModeConnection(now);

  if (result == WebModeStartResult::STARTED) {
    currentState = ApplicationState::WebModeConnecting;
    isWebModeActive = false;
  } else if (result == WebModeStartResult::START_FAILED) {
    LOG_ERROR("[handleWebModeToggle] Web Mode start failed.");
    disconnectWiFi();
  } else if (result == WebModeStartResult::NO_CREDENTIALS) {
    LOG_INFO(
        "[handleWebModeToggle] No credentials saved, starting provisioning.");
    startProvisioning();
  }
}

/**
 * @brief Exits web mode and restores the current insult or empty-state screen.
 *
 * Stops the web server, ends mDNS if active, and disconnects Wi-Fi.
 */
static void handleExitWebMode() {
  webServerManager.stop();
  exitWebMode();
  isWebModeActive = false;
  LOG_INFO("[WebMode] Exited successfully.");
  if (insultsHasAny()) {
    displayRenderInsult(insultsGetCurrentText());
  } else {
    displayRenderEmptyState();
  }
}

/**
 * @brief Handle a debounced button intent event and apply app-level behavior.
 *
 * Input gating:
 * - Events are ignored during a short post-boot/post-wake window to prevent
 *   accidental triggers from startup jitter or a button held during reset.
 *
 * Sleep button behavior (allowed in any state):
 * - HoldStart arms sleep.
 * - HoldEnd triggers deep sleep if sleep was armed ("hold → release to sleep").
 * - Tap cancels any pending arming; in provisioning confirmation it also
 *   returns to idle and restores the insult or empty-state screen.
 *
 * Random/Next/Prev behavior:
 * - In provisioning confirmation, a Next tap starts provisioning; other
 *   non-Sleep events are ignored.
 * - Otherwise, only processed while in Idle and outside web mode.
 * - Tap attempts the corresponding insult operation and transitions to Updating
 *   when an operation starts.
 */
static void handleButtonEvent(ButtonId buttonId, ButtonEvent event,
                              uint32_t now) {
  if (event == ButtonEvent::None) {
    return;
  }

  // Ignore all button intent events for a short window after boot/wake.
  // Wraparound-safe check.
  if (static_cast<int32_t>(now - ignoreInputUntil) < 0) {
    sleepArmed = false;
    return;
  }

  // Sleep button is special; it’s allowed in any state.
  if (buttonId == ButtonId::Sleep) {
    if (event == ButtonEvent::HoldStart) {
      sleepArmed = true;
      ledShowSleep();
      LOG_DEBUG("[Sleep] HoldStart (armed). Release to sleep.");
      return;
    }
    if (event == ButtonEvent::HoldEnd) {
      if (sleepArmed) {
        LOG_DEBUG("[Sleep] HoldEnd (released). Going to sleep.");
        sleepArmed = false;
        enterSleep();
      }
      return;
    }
    if (event == ButtonEvent::Tap) {
      sleepArmed = false;
      if (currentState == ApplicationState::ProvisioningConfirmation) {
        currentState = ApplicationState::Idle;
        if (insultsHasAny()) {
          displayRenderInsult(insultsGetCurrentText());
        } else {
          displayRenderEmptyState();
        }
      } else {
        restoreLedForState();
      }
      return;
    }
  }

  // Provisioning Confirmation buttons mean different things.
  if (currentState == ApplicationState::ProvisioningConfirmation) {
    if (event != ButtonEvent::Tap) {
      return;
    }
    if (buttonId == ButtonId::Next) {
      startProvisioning();
      return;
    }
    return;
  }

  // For Random/Next/Prev we only start work from Idle and outside Web Mode.
  if (currentState != ApplicationState::Idle || isWebModeActive) {
    return;
  }

  if (event == ButtonEvent::Tap) {
    switch (buttonId) {
      case ButtonId::Random:
        LOG_DEBUG("[Random] Tap");
        if (insultsStartOperation(PendingAction::Random, now)) {
          enterUpdating();
        }
        break;

      case ButtonId::Next:
        LOG_DEBUG("[Next] Tap");
        if (!gestureActive && !gestureTriggered) {
          if (insultsStartOperation(PendingAction::Next, now)) {
            enterUpdating();
          }
        }
        break;

      case ButtonId::Prev:
        LOG_DEBUG("[Prev] Tap");
        if (!gestureActive && !gestureTriggered) {
          if (insultsStartOperation(PendingAction::Prev, now)) {
            enterUpdating();
          }
        }
        break;

      default:
        break;
    }
  }
}

/**
 * @brief Handles long-press gestures for provisioning and web mode.
 *
 * While idle, holding Next, Prev, and Random for two seconds starts
 * provisioning or requests confirmation when credentials are saved. Holding
 * Next and Prev for two seconds starts a web mode connection attempt or exits
 * active web mode. Connection results are handled by loop().
 *
 * @param now Current uptime in milliseconds, used to time the held gesture.
 */
static void handleButtonGestures(uint32_t now) {
  const bool webmodeGesture = nextButton.state == ButtonState::Pressed &&
                              prevButton.state == ButtonState::Pressed;

  const bool provisioningGesture = nextButton.state == ButtonState::Pressed &&
                                   prevButton.state == ButtonState::Pressed &&
                                   randomButton.state == ButtonState::Pressed;

  if (provisioningGesture && currentState == ApplicationState::Idle) {
    if (!gestureActive || !gestureIsProvisioning) {
      gestureActive = true;
      gestureStartedAt = now;
      gestureTriggered = false;
      gestureIsProvisioning = true;
    } else if (!gestureTriggered && now - gestureStartedAt >= 2000) {
      if (hasKnownNetwork()) {
        displayRenderMessage(
            "Wifi Already configured, change/add settings?, "
            "press Next to confirm, or Sleep to cancel.");
        currentState = ApplicationState::ProvisioningConfirmation;
      } else {
        startProvisioning();
      }
      gestureTriggered = true;
    }
  } else if (webmodeGesture && currentState == ApplicationState::Idle) {
    if (!gestureActive || gestureIsProvisioning) {
      gestureActive = true;
      gestureStartedAt = now;
      gestureTriggered = false;
      gestureIsProvisioning = false;
    } else if (!gestureTriggered && now - gestureStartedAt >= 2000) {
      if (!isWebModeActive) {
        handleWebModeToggle(now);
      } else {
        handleExitWebMode();
      }
      gestureTriggered = true;
    }
  } else {
    gestureActive = false;
    gestureStartedAt = 0;
    gestureTriggered = false;
    gestureIsProvisioning = false;
  }
}

// ───────────────── Arduino lifecycle ─────────────

/**
 * @brief Initializes the device for a cold boot or wake from deep sleep.
 *
 * Configures hardware, restores persistent insult state, renders the
 * appropriate display content, and enters the boot state.
 */
void setup() {
  Serial.begin(115200);
  delay(50);

  if (!LittleFS.begin(true)) {
    LOG_ERROR("LittleFS mount failed — restarting");
    Serial.flush();
    ESP.restart();
  }

  bool wokeFromSleep = false;
  {
    Preferences prefs;
    if (prefs.begin(NVS_NS, false)) {
      const uint8_t slept = prefs.getUChar("slept", 0);
      wokeFromSleep = (slept == 1);

      // IMPORTANT: do NOT clear here.
      // We clear later (after boot splash) so monitor reconnect/reset can't
      // hide the wake classification.
      needsSleepFlagClear = wokeFromSleep;

      prefs.end();
    }
  }

  LOG_INFO("");
  LOG_INFO("Booting Bard's Assistant...");

  // Seed RNG for deck shuffling
  randomSeed(esp_random());

  // Ignore intent events briefly after boot/wake.
  ignoreInputUntil = millis() + 200;

  ledInit();

  // After EXT0 deep-sleep wake, the wake pin may be latched as RTC IO.
  // Deinit it so we can use it as a normal GPIO with INPUT_PULLUP.
  // On cold boot this is a no-op (returns error, which we ignore).
  rtc_gpio_deinit(WAKEUP_GPIO);

  buttonInit(sleepButton, PIN_SLEEP_BUTTON);
  buttonInit(randomButton, PIN_RANDOM_BUTTON);
  buttonInit(nextButton, PIN_NEXT_BUTTON);
  buttonInit(prevButton, PIN_PREV_BUTTON);

  enterBoot();

  if (!displayInit(displayConfig)) {
    LOG_ERROR("Display init failed");
  }

  // Initialize insults state (restores from NVS on wake).
  insultsInit(PRINT_INSULT_ON_BOOT, wokeFromSleep);

  // Render policy:
  // - Wake: show last insult immediately (screen was blanked before sleep).
  // - Cold boot: show an insult only if PRINT_INSULT_ON_BOOT is enabled.
  if (insultsHasAny()) {
    if (wokeFromSleep) {
      displayRenderInsult(insultsGetCurrentText());
    } else if (PRINT_INSULT_ON_BOOT) {
      displayRenderInsult(insultsGetCurrentText());
    }
  } else {
    displayRenderEmptyState();
  }
}
/**
 * @brief Polls device inputs, advances the application state, and services
 * the web server.
 *
 * Processes debounced button events, transitions from the boot splash to
 * idle, advances active insult operations, and renders completed operations
 * before returning to the idle state. It also polls Wi-Fi provisioning,
 * starts web mode after successful configuration, and services web requests
 * whenever web mode is active.
 *
 * Polls pending web mode connections and starts the server on success, showing
 * the hostname or the IP address if mDNS fails. A failed connection disconnects
 * Wi-Fi and displays an error. Either outcome returns to idle.
 */
void loop() {
  const uint32_t now = millis();

  // Poll buttons
  const ButtonEvent sleepEvent = updateButton(sleepButton, now);
  const ButtonEvent randomEvent = updateButton(randomButton, now);
  const ButtonEvent nextEvent = updateButton(nextButton, now);
  const ButtonEvent prevEvent = updateButton(prevButton, now);

  handleButtonEvent(ButtonId::Sleep, sleepEvent, now);
  handleButtonEvent(ButtonId::Random, randomEvent, now);
  handleButtonEvent(ButtonId::Next, nextEvent, now);
  handleButtonEvent(ButtonId::Prev, prevEvent, now);

  // enable/disable webMode
  handleButtonGestures(now);

  // High-level app state machine
  switch (currentState) {
    case ApplicationState::Boot:
      if (now - stateEnteredAt >= LED_BOOT_DURATION_MS) {
        enterIdle();
      }
      break;

    case ApplicationState::Idle:
      break;

    case ApplicationState::Updating:
      if (insultsPoll(now)) {
        onOperationCompleted();
      }
      break;
    case ApplicationState::Provisioning: {
      ProvisioningPollResult pollResult = provisioningPoll();
      if (pollResult == ProvisioningPollResult::SUCCESS) {
        provisioningState = ProvisioningState::Success;
        WebModeResult webRes = enterWebModeAlreadyConnected();
        if (webRes == WebModeResult::SUCCESS) {
          webServerManager.start();
          isWebModeActive = true;
          char msg[64];
          snprintf(msg, sizeof(msg), "WiFi saved!\n%s.local\n%s",
                   BARDS_HOSTNAME, WiFi.localIP().toString().c_str());
          displayRenderMessage(msg);
        } else if (webRes == WebModeResult::MDNS_FAILED) {
          webServerManager.start();
          isWebModeActive = true;
          char msg[64];
          snprintf(msg, sizeof(msg), "WiFi saved!\n%s",
                   WiFi.localIP().toString().c_str());
          displayRenderMessage(msg);
        } else {
          displayRenderMessage("WiFi saved!\nCouldn't start web mode.");
        }
        currentState = ApplicationState::Idle;
      } else if (pollResult == ProvisioningPollResult::FAILED) {
        provisioningState = ProvisioningState::Failed;
        currentState = ApplicationState::Idle;
        displayRenderMessage("WiFi setup cancelled/failed.");
      } else if (pollResult == ProvisioningPollResult::CANCELLED) {
        provisioningState = ProvisioningState::Idle;
        currentState = ApplicationState::Idle;
        if (insultsHasAny()) {
          displayRenderInsult(insultsGetCurrentText());
        } else {
          displayRenderEmptyState();
        }
      }
      break;
    }
    case ApplicationState::ProvisioningConfirmation: {
      break;
    }
    case ApplicationState::WebModeConnecting: {
      WebModePollResult result = pollWebModeConnection(now);

      if (result == WebModePollResult::SUCCESS) {
        currentState = ApplicationState::Idle;

        MDNSResult mdnsRes = startMDNS();

        if (mdnsRes == MDNSResult::MDNS_FAILED) {
          currentState = ApplicationState::Idle;

          isWebModeActive = true;
          webServerManager.start();

          displayRenderMessage(WiFi.localIP().toString().c_str());
        } else {
          isWebModeActive = true;
          webServerManager.start();
          displayRenderMessage(
              "Web Mode Activated. Visit BardsAssistant.local in the browser.");
        }

      } else if (result == WebModePollResult::FAILED) {
        currentState = ApplicationState::Idle;

        isWebModeActive = false;
        disconnectWiFi();

        displayRenderMessage("Error activating Web Mode.");

      } else if (result == WebModePollResult::IN_PROGRESS) {
        // Nothing to do; keep polling next loop.
      }
      break;
    }
  }
  if (isWebModeActive) {
    webServerManager.handle();
  }
}

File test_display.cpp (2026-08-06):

#include <Arduino.h>
#include <SPI.h>
#include <GxEPD2_BW.h>
#include <epd/GxEPD2_213_B74.h>

static const int EPD_RST  = 8;
static const int EPD_DC   = 9;
static const int EPD_CS   = 10;
static const int EPD_BUSY = 11;
static const int EINK_SCK  = 13;
static const int EINK_MOSI = 12;
static const int EINK_MISO = -1;

SPIClass hspi(HSPI);
GxEPD2_BW<GxEPD2_213_B74, GxEPD2_213_B74::HEIGHT> display(
    GxEPD2_213_B74(EPD_CS, EPD_DC, EPD_RST, EPD_BUSY)
);

void setup() {
  Serial.begin(115200);
  delay(1500);
  Serial.println("GxEPD2 + HSPI test");

  hspi.begin(EINK_SCK, EINK_MISO, EINK_MOSI, -1);
  display.epd2.selectSPI(hspi, SPISettings(4000000, MSBFIRST, SPI_MODE0));

  display.init(115200, true, 2, true);
  display.setRotation(1);
  display.setFullWindow();

  display.firstPage();
  do {
    display.fillScreen(GxEPD_WHITE);
    display.drawRect(0, 0, display.width(), display.height(), GxEPD_BLACK);
    display.setTextColor(GxEPD_BLACK);
    display.setTextSize(2);
    display.setCursor(10, 28);
    display.print("HELLO");
    display.setTextSize(1);
    display.setCursor(10, 55);
    display.print("PlatformIO works!");
  } while (display.nextPage());

  Serial.println("Done.");
}

void loop() {}

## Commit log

2025-12-26 Button and LED modules
2025-12-26 led and button modules
2025-12-26 Fix include directive formatting in main.cpp
    [main.cpp]
2025-12-26 📝 Add docstrings to `feature/led-module-fixed`
    Docstrings generation was requested by @jaylingelbach.
    * https://github.com/jaylingelbach/BardAssistant/pull/1#issuecomment-3693447027
    The following files were modified:
    * `lib/button/button.cpp`
    * `lib/led/led.cpp`
    * `src/main.cpp`
    [main.cpp]
2025-12-27 adjust led brightness
2025-12-27 📝 Add docstrings to `feature/render-insults-serial`
    * https://github.com/jaylingelbach/BardAssistant/pull/3#issuecomment-3694201604
    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
    [main.cpp]
2025-12-28 cleaup dead branch of code and fix docstring
    [main.cpp]
2025-12-28 Restore LED state when sleep is cancelled.
2025-12-28 if error in wakeup, log.
    [main.cpp]
2025-12-28 error handling for sleep
    [main.cpp]
2026-08-05 Wire e-ink display into main firmware via HSPI
    - Display module: full implementation of displayInit, displayRenderInsult,
    displayRenderBlankScreen, displaySleep, and text wrapping
    - Fix SPI bus: use HSPI (GPIO 12/13) instead of default FSPI; add selectSPI
    call before init so GxEPD2 uses the correct peripheral
    - platformio.ini: add S3-Zero variant/flags, DIO flash mode, test-display env
    - insults: expose insultsGetCurrentText, insultsGetCurrentIndex, insultsHasAny
    - main: integrate display into boot/wake/sleep/operation-complete flow
    [main.cpp]
2026-08-06 Add S3-Zero board variant to repo for portable builds
    Copies variants/waveshare_esp32_s3_zero/pins_arduino.h into the repo and
    updates board_build.variants_dir to the repo-relative path so the build
    works on any machine without a local Arduino15 installation.
2026-08-06 Fix pulldown_rst_mode comment and remove redundant BUSY pinMode
    - display.cpp: correct init() comment from pulldown_busy to pulldown_rst_mode
    - test_display.cpp: remove pinMode(EPD_BUSY, INPUT_PULLUP); GxEPD2 sets BUSY
    to INPUT inside init() and the B74 panel drives it actively
    [test_display.cpp]
2026-08-06 Decouple pulldown_rst_mode from BUSY wiring in displayInit
    Add pulldownRstMode field to DisplayConfig (defaults true for B74) and
    pass it explicitly to GxEPD2 init() instead of reusing useBusy, which
    controls a different concern.
2026-08-06 Fix display rotation and sanitize Unicode for GFX font
    - Default rotation R1 -> R3 (landscape, connector at bottom)
    - Add sanitizeForDisplay helper to replace curly/straight apostrophes
    with backtick, which renders cleanly at size 2 in the GFX bitmap font
    - Decouple pulldownRstMode from useBusy in DisplayConfig
2026-08-09 Add LittleFS support and migrate insults to std::vector
    - Mount LittleFS on boot and print insults.txt contents to serial
    - Migrate insults from static array to std::vector<std::string>
    - Fix deck vector crash: resize before index-based writes
    - Add .c_str() calls where const char* is required from std::string
    - Add data/ directory with insults.txt for LittleFS upload
    [main.cpp]
2026-08-18 Add KiCad PCB project
    [BardsAssistant.kicad_pcb, BardsAssistant.kicad_sch]
2026-08-18 Ignore KiCad backup zips and remove from tracking
2026-08-18 Remove debug file-print from setup
2026-08-18 Restart on LittleFS mount failure instead of returning from setup
    [main.cpp]
2026-08-18 Vendor ESP32-S3-MINI-1-N8 KiCad library and use project-relative paths
2026-08-18 Ignore KiCad ERC.json and remove from tracking
2026-08-18 Fix LED footprint description to reference correct XinLight part
2026-08-18 Ignore and untrack .kicad_prl local UI state files
2026-08-18 Fix stale filename metadata in BardsAssistant.kicad_pro
2026-08-21 Added new KiCad revision
    [BardsAssistant.csv, BardsAssistant.kicad_sch]
2026-09-01 updated pcb v1
    [BardsAssistant-B_Cu.gbr, BardsAssistant-B_Mask.gbr, BardsAssistant-B_Paste.gbr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]
2026-09-04 Add NetworkManager, WebServerManager, and web UI
    - Add NetworkManager with setupWiFi(), enterWebMode(), exitWebMode()
    - Add WebServerManager serving LittleFS static files and JSON API
    - GET /api/decks?id=insults returns insults as [{id, text}] JSON
    - POST /api/decks/data stub for future deck writes
    - Serve index.html, style.css, app.js from LittleFS via onNotFound handler
    - Web UI: insults page with card layout, add insult dialog, primary/secondary buttons
    - Fix main.cpp: move setupWiFi() to setup(), remove from loop()
2026-09-04 Update KiCad schematic, PCB, and library files
    - Update schematic and PCB layout
    - Add LED-SMD-SM1210RGB footprint to BardAssLibrary
    - Remove old Gerber exports and production files, update with new
    - Remove BAV1.zip
    [BardsAssistant-B_Cu.gbr, BardsAssistant-B_Mask.gbr, BardsAssistant-B_Paste.gbr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]
2026-09-04 Fix LED symbol to reference Bivar SM1210RGB consistently
    - Update footprint to BardAssLibrary:LED-SMD-SM1210RGB
    - Update MPN from XL-3227RGB-RF to SM1210RGB
    - Update manufacturer from XINGLIGHT to Bivar
2026-09-05 update d-, d+ connection
    [BardsAssistant.kicad_sch]
2026-09-05 Refine NetworkManager, WebServerManager, and web UI
    - Add exitWebMode() with mDNS teardown and isMdnsRunning guard
    - Reduce enterWebMode() connection timeout to 5s
    - Add ExitWebModeResult enum to networkManager.h
    - Standardize API error responses to JSON {error: ...} via sendError helper
    - Add btn-secondary class (outlined, pairs with btn-primary)
    - Add btn-small class for inline list actions
    - Center dialog with fixed positioning, modern shadow and backdrop blur
    - Style input fields with focus ring
    - Fix API_BASE to always point at bardsassistant.local
    [main.cpp]
2026-09-06 📝 Add docstrings to `feature/network-web-api`
    * https://github.com/jaylingelbach/BardAssistant/pull/14#issuecomment-5560933427
    * `data/app.js`
    * `lib/insults/insults.cpp`
    * `lib/network/networkManager.cpp`
    * `lib/web/webServerManager.cpp`
    * `lib/web/webServerManager.h`
    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
    [main.cpp]
2026-09-07 📝 Add docstrings to `feature/migrate-insults.txt-to-json`
    * https://github.com/jaylingelbach/BardAssistant/pull/16#issuecomment-5576829255
    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
    [main.cpp]
2026-09-11 feat: full deck CRUD API with JS UI, ID-based history, and generic result types
    - Add POST/PUT/DELETE /api/decks endpoints with full validation and error handling
    - Refactor deck and history from index-based to ID-based (uint32_t) for safe deletes
    - Add safe-write pattern for insults.json (.tmp -> .bak -> rename)
    - Add displayRenderEmptyState() for boot and post-delete empty deck
    - Add cross-deck repeat prevention in drawFromDeck
    - Fix removeFromHistory to remove ALL occurrences and correctly reposition historyHead
    - Move DeckEntry/DeckEntryResult/DeleteDeckEntryResult to shared deckTypes.h for multi-deck support
    - Add edit and delete modals to app.js with confirmation dialog
    - Upgrade to C+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
    [main.cpp]
2026-09-11 Invalidate a deleted ID’s pending operation before polling
2026-09-12 chore: add compile_commands generation and dev setup docs
    Adds generate_compile_commands.py so clangd-powered Go to Definition
    works in VS Code, and documents the setup in docs/dev-setup.md.
2026-09-15 Power down Wi-Fi after a connection failure.
2026-09-17 feat: add compile-time leveled logging via log.h
    Introduces lib/include/log.h with LOG_ERROR/WARN/INFO/DEBUG macros
    gated by a LOG_LEVEL compile flag. Output below the active level is
    stripped entirely at compile time — no flash strings, no runtime cost.
    Default is LOG_LEVEL=4 (DEBUG) in platformio.ini. Set to 3 for release
    builds to remove all debug output (button taps, WiFi dots, title cards).
    Replaces all raw Serial.print/println/printf calls across main.cpp,
    insults.cpp, networkManager.cpp, webServerManager.cpp, and display.cpp.
    Removes the old ENABLE_APP_LOGS / APP_LOGLN pattern from main.cpp.
    Adds a Logging section to docs/dev-setup.md covering levels, how to
    change the build flag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
    [main.cpp]
2026-09-18 Reset gesture tracking when the active gesture changes.
    [main.cpp]
2026-09-21 fix(clangd): silence ESP32 toolchain false positives on Apple clangd 17
    Remove bad --target=xtensa flag (caused GCC probe to fail with rc=1),
    add block_on_nonlocal suppression for __block in unistd.h, and add
    #include <stdint.h> to provisioning.h for standalone header parsing.
2026-09-21 Framework for polling provisioning laid down
2026-09-22 feat(provisioning): non-blocking WiFi provisioning flow
    - Non-blocking WiFiManager portal (setConfigPortalBlocking(false) + process() polling)
    - ProvisioningConfirmation state: if network already saved, prompt before re-provisioning
    - Confirmation only fires on Tap to prevent immediate trigger from gesture hold-release
    - Success/failure display feedback: "WiFi saved!" / "WiFi setup cancelled/failed."
    - Credentials-failed detection via setSaveParamsCallback + setConnectRetries(1)
    - hasKnownNetwork() initializes WiFi driver before querying to avoid stale reads
    - displayRenderMessage() replaces displayRenderWebModeState() as generic text renderer
    - resetWiFiSettings() helper for dev NVS wipe (W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
    [main.cpp]
2026-09-22 fix(provisioning): close portal immediately on bad credentials
    - Move cancel logic into Sleep Tap handler so it isn't swallowed by the
    sleep button's early return
    - Force-close portal via stopConfigPortal() when credentials were
    submitted but connection failed, instead of waiting for 3-min timeout
    [main.cpp]
2026-09-22 fix(provisioning): correct IP display, deduplicate WiFi init, silence build warnings
    - Add enterWebModeAlreadyConnected() for post-provisioning web mode entry;
    skips WiFi.begin() since WiFiManager already holds a live connection,
    preventing 0.0.0.0 IP from re-init race
    - Wait for non-zero IP in enterWebMode() connection loop
    - Centralize hostname via BARDS_HOSTNAME; remove duplicate hardcoded strings
    - Remove ARDUINO_VARIANT from build_flags (already set by board_build.variant),
    eliminating macro-redefined warnings on every compile
    [main.cpp]
2026-09-22 fix(provisioning): improve portal instructions display message
    [main.cpp]
2026-09-22 Show only the IP address when mDNS fails.
    [main.cpp]
2026-09-22 Document Wi-Fi provisioning, button controls, and display message behavior
2026-09-22 Show the mDNS-failure fallback in the flow.
2026-09-25 Disconnect Wi-Fi on both connection-failure paths.
    [main.cpp]
2026-09-25 Start the web server when mDNS fails.
    [main.cpp]
2026-10-06 Milestone 5: replace single-network assumptions, add debug logging
    Updates hasKnownNetwork() to use credential store instead of WiFiManager.
    Adds diagnostic logs to provisioning callback and WiFiMulti connection
    flow. Includes credentialStore.h in main.cpp.
    [main.cpp]
2026-11-02 Add on-device menu system with e-ink rendering
    Implements a navigation menu opened by long-pressing Random from Idle.
    Menu module (lib/menu/) owns navigation state with one-level submenu
    support via parent state variables. MenuItem carries its own children
    pointer so menuSelect() handles submenu entry automatically without
    dedicated action functions.
    Root items: Decks (submenu → Insults), Web Mode (toggle), Settings
    (stub). Next/Prev navigate, Random selects, Sleep tap goes back or
    exits to Idle. Display renders selected item inverted (white text on
    black fill) at text size 2.
2026-11-02 Document menu APIs, rendering edge cases, and button handling
    <!-- coderabbit-ai-generated:v1 -->
